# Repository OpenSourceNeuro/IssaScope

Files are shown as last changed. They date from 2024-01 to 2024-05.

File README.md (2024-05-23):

<p align="left">
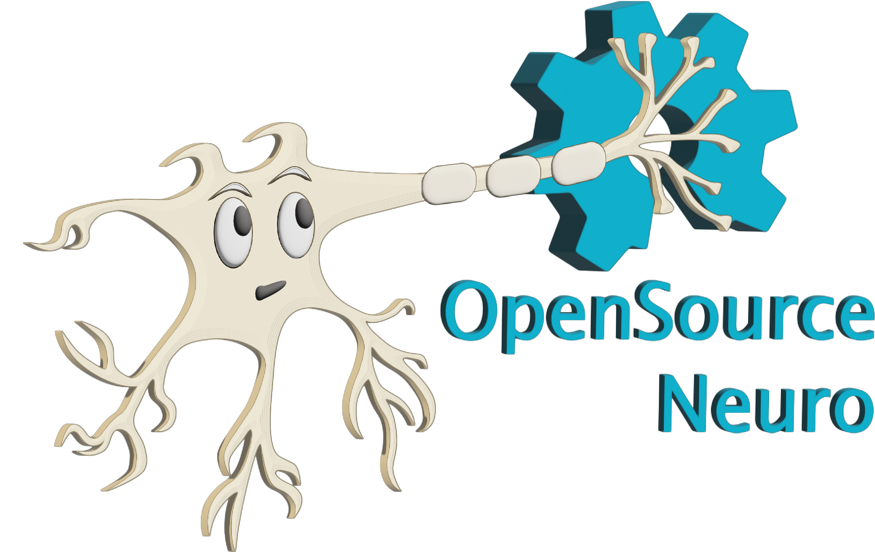
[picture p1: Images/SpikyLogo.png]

</p>

<h1 align="center"> Issa Scope v0.2</h1>
<h3 align="center">  An ethoscope for optogenetics behavioural essays</h3></p>
<h6 align="right">developed by M.J.Y. Zimmermann</h6>

<br></br>

This project is licensed under the <a href="https://www.gnu.org/licenses/gpl-3.0.html">GNU General Public License v3.0</a>

The hardware is licensed under the <a href="https://cern-ohl.web.cern.ch">CERN OHL v1.2</a>

<br></br>

***

<br></br>

- [Introduction](#Introduction)
- [EthoScope](#Ethoscope)
- [PCB](#PCB)
- [ESP32/Arduino microcontroller](#Microcontroller)
  - [Driver Installation](#Driver_Installation)
  - [Arduino Environment](#Arduino_IDE)
  - [Compiling and uploading code](#Compiling_the_code)
- [GUI](#GUI)
  - [PyQt Script](#PyQt)
  - [Scope Software](#Software)

- [To-Do-List](#To-Do-List)

<br></br>

***

<br></br>

## Introduction

<br></br>

## Ethoscope
<p align="justify">
The Ethoscope consists of 15mm extruded aluminium bars purchased from <a href="https://www.makerbeam.com/makerbeamxl/">MakerBeam</a> (XL profile), and 3D printed parts.
</p>

<br></br>

## PCB
<br>
<div align= "justify">

<p>
Dedicated PCBs for all electronics components contained in the scope base and platform stimulating LEDs can be found <a href="https://github.com/OpenSourceNeuro/IssaScope/tree/main/PCB"><strong>here</strong></a> along with detailed instructions to reproduce and adapt them.
</p>

<br></br>
<h3 align="left">Ethoscope Main Board</h3></p>

<p>
The PCB is built around an <a href="https://www.espressif.com/en/products/socs/esp32">ESP32</a>, a microcontroller which exchanges signals with the recording setup, and the <a href="https://www.ti.com/lit/ds/symlink/tlc5947.pdf">TLC5947 LED driver</a>, which allows linear intensity control over all stimulating lights. The microcontroller runs on C++ however, users do not need to interfere with the source code as we provide an intuitive and interactive <a href="">Graphical User Interface</a> (GUI), from which all functions and variables can be manipulated.
</p>

<p align="center">
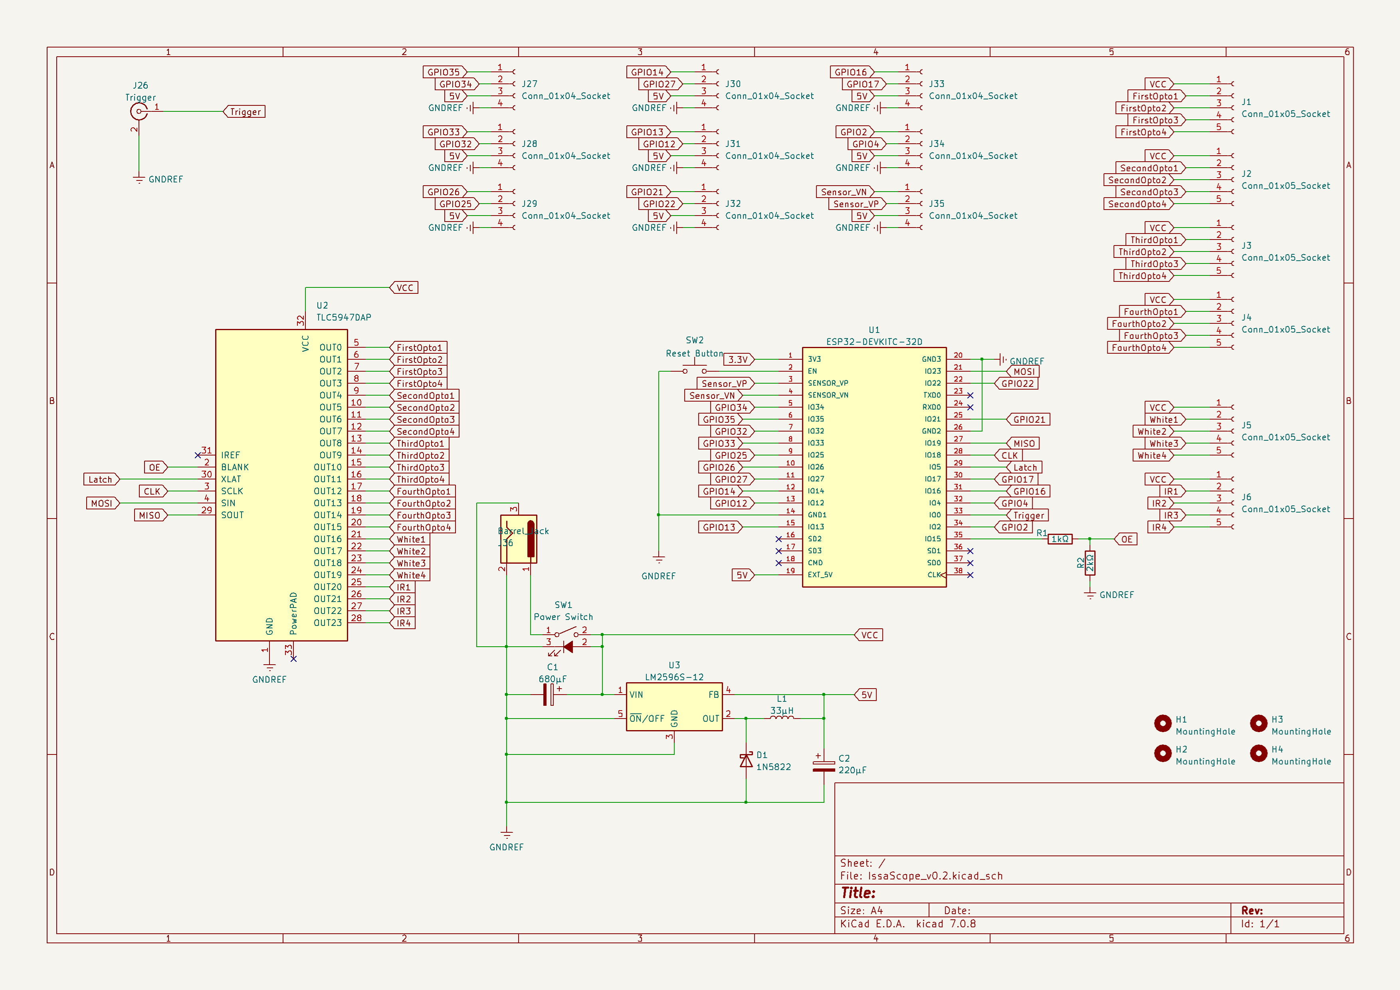
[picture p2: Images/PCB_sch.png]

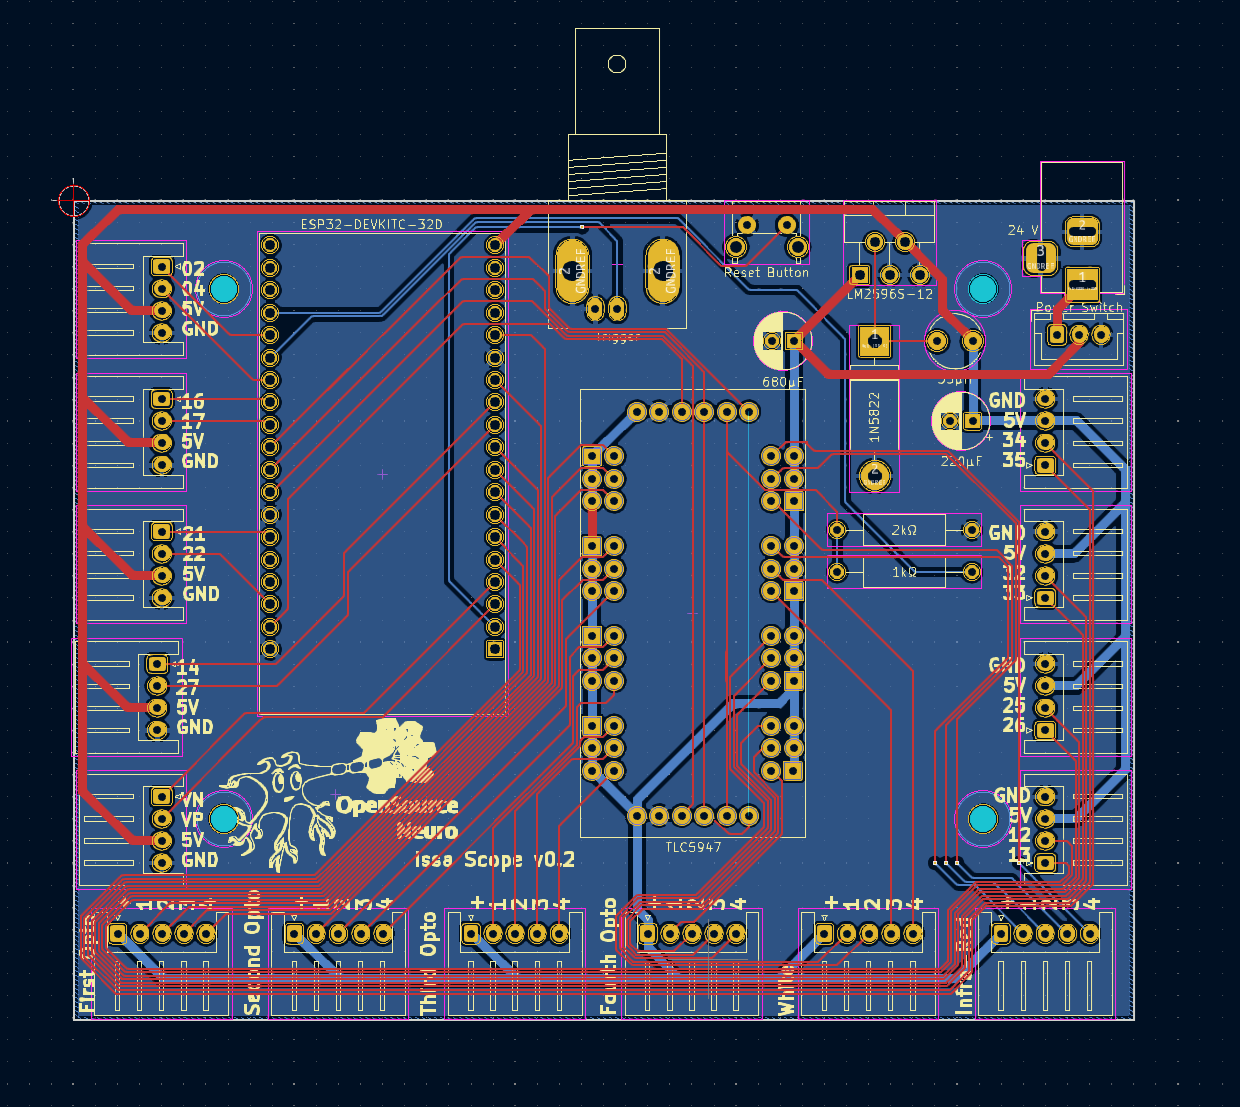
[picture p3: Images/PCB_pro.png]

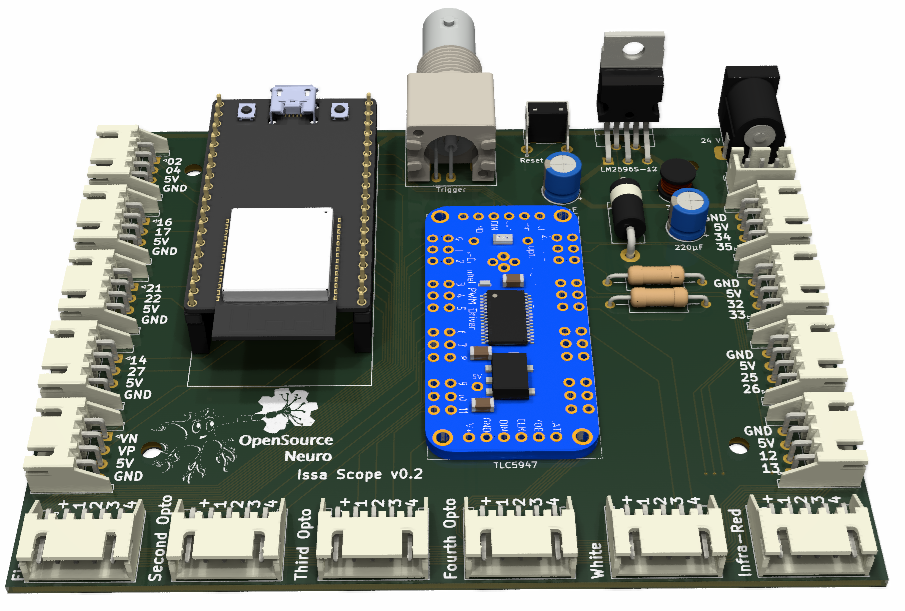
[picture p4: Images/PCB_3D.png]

</p>

<h5 align="center"> <em>Left: </em>PCB schematics for the IssaScope v0.2, <em>Middle: PCB layout for manufacturing</em>, <em>Right: </em>Rendering of the board populated with electronics components</h5>

<br>

<p>
The board provides connections via Molex JST plugs for 4 * four LED channels meant to be used for 4 * four distinct optogenetics light sources.

It also provides ports for base illumination for both white and infra red lights, designed for providing light below the samples.

Remaining ports provide access to unuse GPIO pins on the microcontroller for further upgrade (I/O signals, sensors, motors, etc.)

The board takes a 24V input, a tension above this value will result in damaging the board components.
</p>

<br></br>

<p>
This repository contains detailed <a href="https://github.com/OpenSourceNeuro/OpenSpritzer-V2/blob/main/Installation_Manual.md">assembly instructions and an operation manual</a> for the Scope electronics assembly. The <a href="https://github.com/OpenSourceNeuro/OpenSpritzer-V2/blob/main/BOM.csv">bill of material</a> details all components required.
</p>

<p>
To simplify the wiring assembly, a customed circuit board has been designed. PCB prototype companies (i.e. <a href="jlcpcb.com"> JLCPCB</a>) will only require the <a href="https://github.com/OpenSourceNeuro/IssaScope/tree/main/PCB/IssaScope_gerbers  "> gerber.zip</a> folder to be sent to them for production.
</p>

</div>
<br></br>

## Microcontroller

#### Driver_Installation
<br>
<div align= "justify">

<p>
IssaScope v0.2 firmware runs on an Espressif ESP32 board and requires the USB to UART bridge <a href="https://www.silabs.com/developers/usb-to-uart-bridge-vcp-drivers"> CP210x driver</a>,  which can be downloaded<a href="https://www.silabs.com/developers/usb-to-uart-bridge-vcp-drivers?tab=downloads"> <strong>here</strong></a>.
</p>

<p>
Once the driver has been installed, users can upload and modify the <a href="https://https://github.com/OpenSourceNeuro/IssaScope/tree/main/Arduino/IssaScope.com/OpenSourceNeuro/OpenSpritzer-V2/tree/main/Arduino/OpenSpritzer_V2">microcontroller code</a> through the <a href="https://www.arduino.cc/en/software">Arduino IDE</a> (Integrated Development Environment).
</p>

</div>
<br></br>

##### Arduino_IDE
<br>
<div align="justify">

<p>
The ESP32 microcontroller runs a C++ code which can be accessed via the Arduino IDE, which can be downloaded <a href="https://www.arduino.cc/en/software"><strong>here</strong></a>.
</p>

<br></br>

<p>
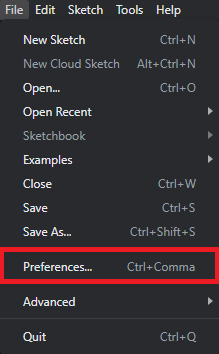
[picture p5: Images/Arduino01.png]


Once the IDE is installed, users needs to install the ESP32 board library:

In the Arduino IDE, go to <strong> File > Preferences </strong>

Enter the following link into the <strong>Additional Board Manager URLs</strong> field:

https://raw.githubusercontent.com/espressif/arduino-esp32/gh-pages/package_esp32_index.json
</p>

<br></br>

<p>
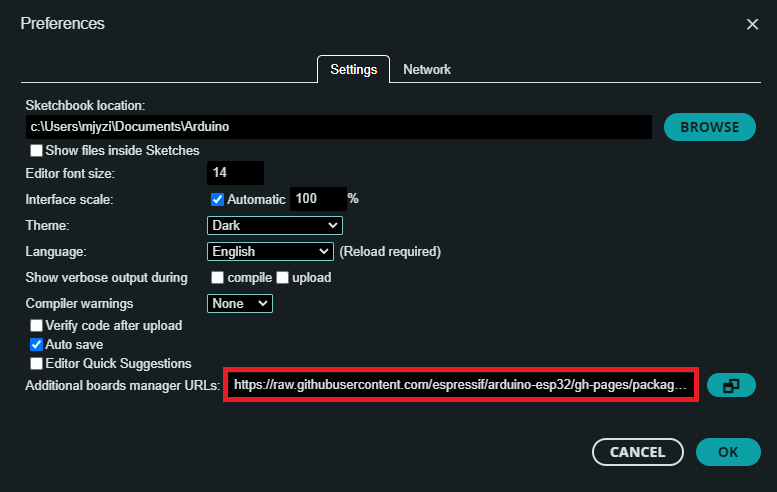
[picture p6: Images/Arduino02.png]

Then click on the <strong>OK</strong> button.
</p>

<br></br>

<p>
Next, open the Boards Manager. Go to <strong> Tools > Board > Board Manager...</strong>

Search for ESP32 and press install button for the <strong>ESP32 by Espressif Systems</strong>.
</p>

<br></br>

<p>
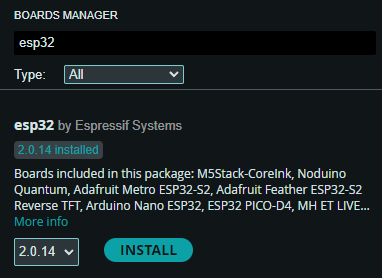
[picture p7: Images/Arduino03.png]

Then click on the <strong>Install</strong> button.
</p>

<br></br>

<p>
Finally and in a smiilar manner the library <strong>Adafruit_TLC5947</strong> needs to be installed.
</p>

</div>
<br></br>

##### Compiling_the_code
<br>
<div align= "justify">

<p>
Within the Arduino IDE, user needs to select the FQBN (Fully Qualified Board Name) on which the code will be compiled for.

Here the ESP32 Dev Module needs to be selected.

Go to <strong>Tools > Board > esp32 > ESP32 Dev Module </strong>


The board name should be displayed  as shown.
</p>

</div>
<br></br>

## GUI
<div align="justify">

<p>
A Graphical User Interface (GUI) dedicated to this project was designed using the python PyQt6/PySide6 libraries. The entire script can be found <a href="https://github.com/OpenSourceNeuro/IssaScope/tree/main/GUI/PyQt"><strong>here</strong></a>.
</p>

</div>
<br></br>

#### PyQt
<br>
<div align="justify">

githubusercontent

<br></br>

#### Software
<br>
<div align="justify">

<p>
The python script for the GUI can be run directly from a python environment, or run from a <strong>.exe</strong> file which can be found <a href=""><strong>here</strong></a>
</p>

<p>
On the main screen, Users can fi
</p>

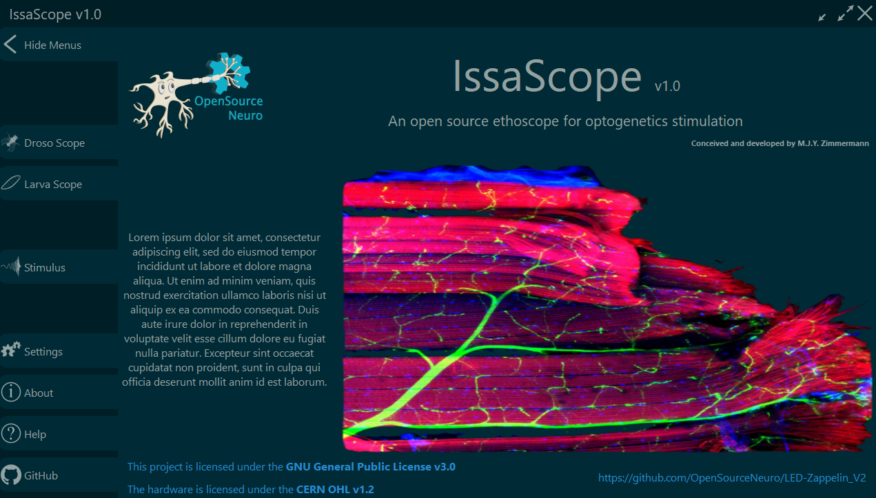
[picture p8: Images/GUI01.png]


</div>
<br></br>

## To-Do-List
<br>
<div align="justify">

- Find suitable material for close up hanging LEDs
- Make an equivalent to the GUI using Bonsai

</div>
<br></br>

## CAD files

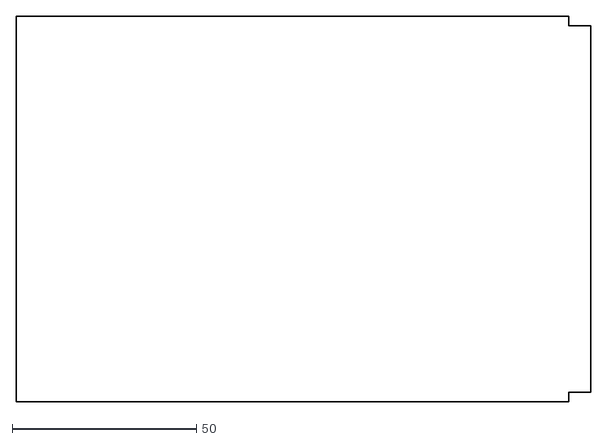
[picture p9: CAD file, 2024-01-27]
3D/DXF/BasePanel.dxf
156.0 x 104.5

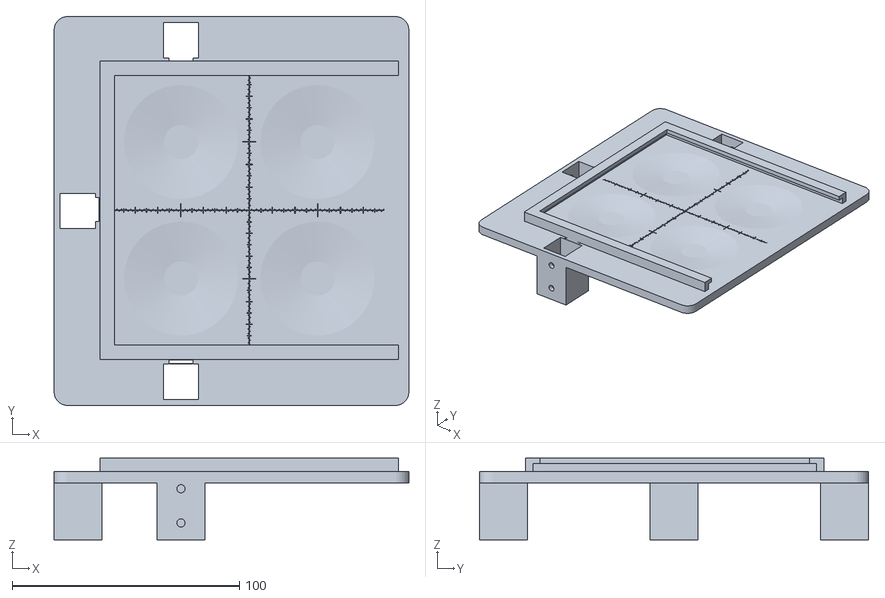
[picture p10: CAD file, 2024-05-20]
3D/STL/IssaScope_Arena.stl
156.0 x 171.0 x 36.0

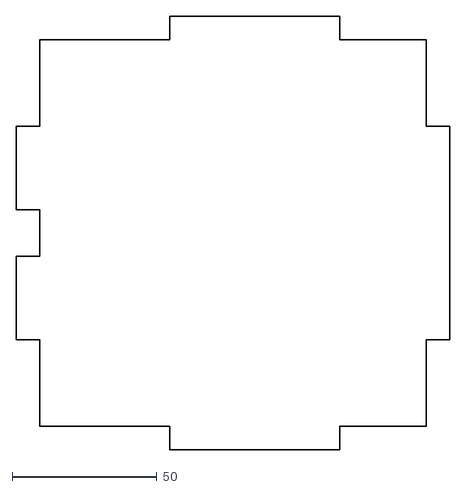
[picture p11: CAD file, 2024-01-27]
3D/DXF/Platform.dxf
150.0 x 150.0

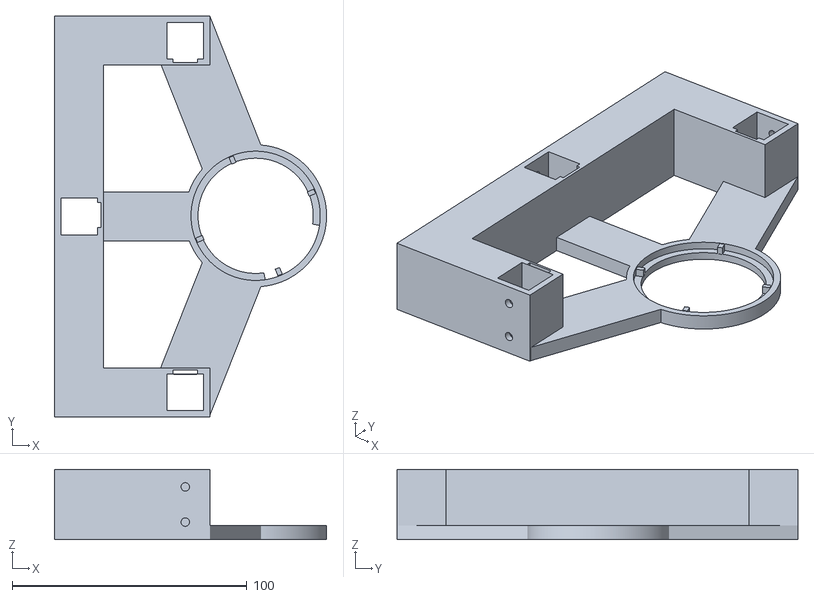
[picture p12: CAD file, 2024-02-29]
3D/STL/IssaScope_IRCamHolder.stl
116.0 x 171.0 x 30.0

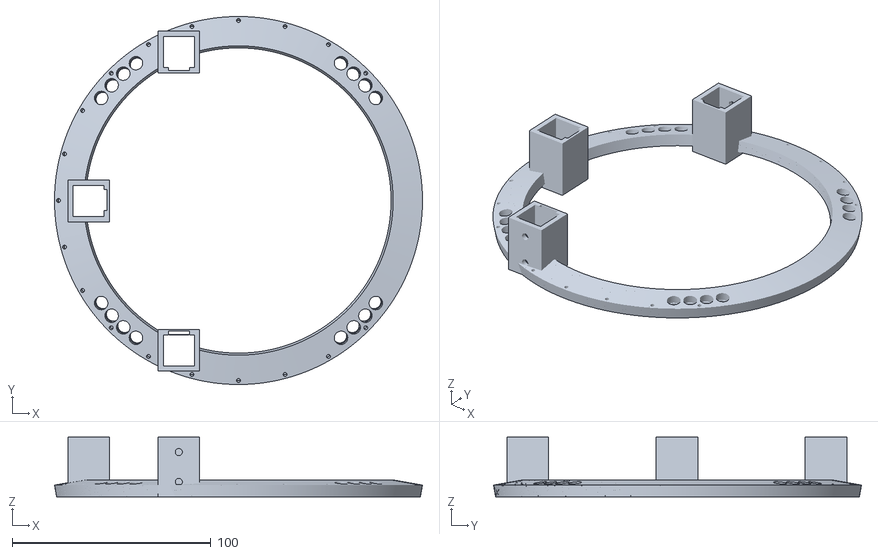
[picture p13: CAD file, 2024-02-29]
3D/STL/IssaScope_Opto.stl
185.0 x 185.0 x 30.0

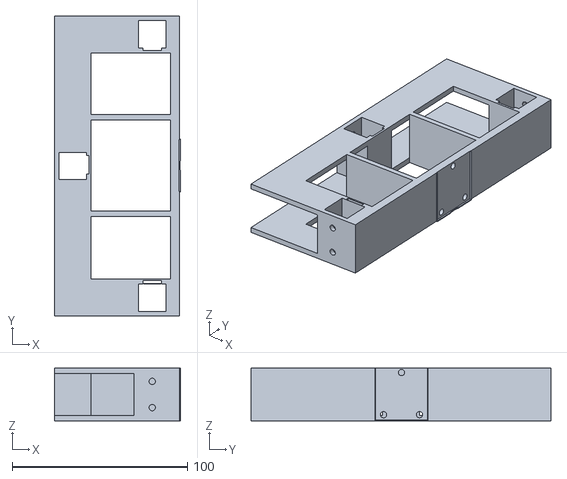
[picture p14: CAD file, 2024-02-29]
3D/STL/IssaScope_BaslerHolder.stl
72.0 x 171.0 x 30.0

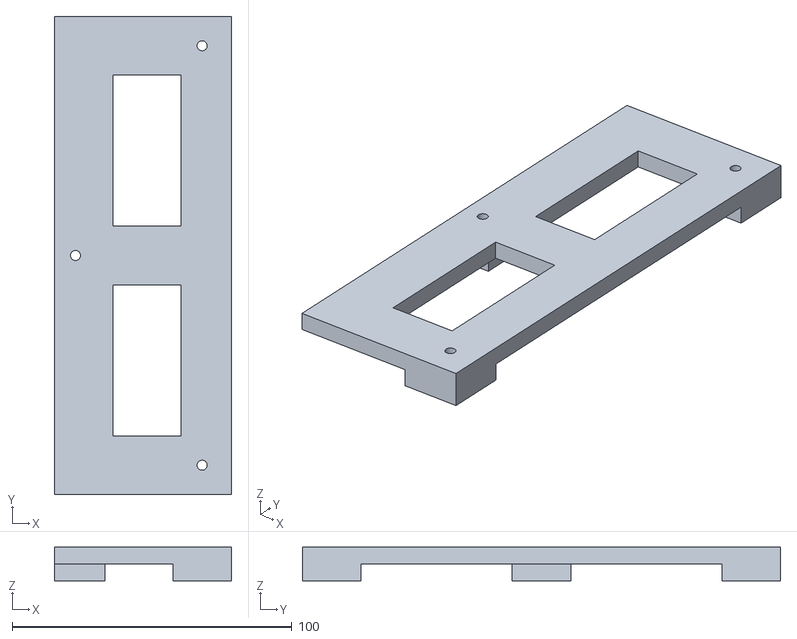
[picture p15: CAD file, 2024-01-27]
3D/STL/IssaScope_Top.stl
63.3 x 171.0 x 12.0

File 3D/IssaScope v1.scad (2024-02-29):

tol = 0.3;
Wall = 3;
M3 = 3/2+tol;
Smoothness = 100;


x_alu = 15;
x_corner = 45;
x_link = 10;
z_link = 1.5+tol;
alu_groove = 3;

z_slider = 30;

l_Extru01 = 150;
l_Extru02 =  50;
l_Extru03 =  300;
l_Extru04 =  200;
LED_Colour = [[1,0,0],[0,1,0],[0,0,1],[1,1,0]];
LED_Colour_Light = [[1,0,0,0.1],[0,1,0,0.1],[0,0,1,0.1],[1,1,0,0.1]];

LED = 5/2;
r_LED = 6.2/2+tol;
R_LED = 7.5/2+tol;
h_LED = 1.5;

Platform = 10;
Base = 10;
Top = 10;
Basler = 10;
Basler_Holder = 10;
IR_Cam_Holder = 1;
Basler_Holder_Full = 1;
LED_Holder = 10;
5mm_LED = 10;
Illumination = 10;
Optogenetics = 10;
 
if (Platform == 1){Platform();}
if (Base == 1){Base();} 
if (Top == 1){Top();} 
if (Basler == 1){translate([0,0,2*x_alu+l_Extru02+2/3*l_Extru03+l_Extru04+z_slider])Basler();} 
if (Basler_Holder == 1){Basler_Holder();} 
if (IR_Cam_Holder == 1){IR_Cam_Holder();} 
if (LED_Holder == 1){LED_Holder();}
if (Optogenetics == 1){translate([0,0,Opto_Height])Optogenetics();}


module Platform(){
    color([0.8,0.8,0.8,0.5])translate([x_alu/2,x_alu/2,l_Extru02+1.5*x_alu])cube([l_Extru01,l_Extru01,Wall]);
}
module Base(){
    translate([0,0,x_alu])rotate([0,90,0]){
        Alu_Extru(l_Extru01);
        translate([0,0,l_Extru01+x_alu])rotate([-90,0,0])Alu_Extru(l_Extru01);
        translate([0,l_Extru01+x_alu,l_Extru01+x_alu])rotate([-180,0,0])Alu_Extru(l_Extru01);
        translate([0,l_Extru01+x_alu,0])rotate([-270,0,0])Alu_Extru(l_Extru01);
    }
    
    translate([x_alu,l_Extru01-x_alu,x_alu])Alu_Extru(l_Extru02);
    translate([l_Extru01-x_alu,l_Extru01-x_alu,x_alu])Alu_Extru(l_Extru02);
    translate([x_alu,x_alu,x_alu])Alu_Extru(l_Extru02);
    translate([l_Extru01-x_alu,x_alu,x_alu])Alu_Extru(l_Extru02);
    
    translate([0,0,x_alu+l_Extru02+x_alu])rotate([0,90,0]){
        Alu_Extru(l_Extru01);
        translate([0,0,l_Extru01+x_alu])rotate([-90,0,0])Alu_Extru(l_Extru01);
        translate([0,l_Extru01+x_alu,l_Extru01+x_alu])rotate([-180,0,0])Alu_Extru(l_Extru01);
        translate([0,l_Extru01+x_alu,0])rotate([-270,0,0])Alu_Extru(l_Extru01);
    }
    
    translate([0,0,2*x_alu+l_Extru02])Alu_Corner();
    translate([l_Extru01+x_alu,0,2*x_alu+l_Extru02])rotate([0,0,90])Alu_Corner();
    translate([l_Extru01+x_alu,l_Extru01+x_alu,2*x_alu+l_Extru02])rotate([0,0,180])Alu_Corner();
    translate([0,l_Extru01+x_alu,2*x_alu+l_Extru02])rotate([0,0,270])Alu_Corner();
    
    translate([x_corner+tol,0,2*x_alu+l_Extru02])Alu_Extru(l_Extru03+l_Extru04);
    translate([x_corner+tol,l_Extru01,2*x_alu+l_Extru02])Alu_Extru(l_Extru03+l_Extru04);
    translate([0,l_Extru01/2,2*x_alu+l_Extru02])Alu_Extru(l_Extru03+l_Extru04);
    
    translate([x_corner-x_alu+tol,0,x_alu+l_Extru02])rotate([90,0,0])Alu_Te();
    translate([x_corner-x_alu+tol,l_Extru01+x_alu+1,x_alu+l_Extru02])rotate([90,0,0])Alu_Te();
    translate([-1,l_Extru01/2-x_alu,x_alu+l_Extru02])rotate([90,0,90])Alu_Te();
}


module Top(){
    translate([x_corner,-Wall,x_alu+l_Extru02+x_alu+l_Extru03+l_Extru04-Wall]){
        difference(){
            union(){
                cube([x_alu+Wall,l_Extru01+x_alu+2*Wall,2*Wall]);
                translate([-x_corner-tol,0,0])cube([x_alu+2*Wall,l_Extru01+x_alu+2*Wall,2*Wall]);
                translate([-x_corner-tol,0,0])cube([x_alu+tol+x_corner,x_alu+2*Wall,2*Wall]);
                translate([-x_corner-tol,l_Extru01,0])cube([x_alu+tol+x_corner,x_alu+2*Wall,2*Wall]);
                translate([-x_corner-tol,l_Extru01/2,0])cube([x_alu+tol+x_corner,x_alu+2*Wall,2*Wall]);
            }
            translate([0,Wall,-tol])cube([x_alu+2*tol,x_alu+2*tol,Wall]);
            translate([0,Wall+l_Extru01,-tol])cube([x_alu+2*tol,x_alu+2*tol,Wall]);
            translate([-x_corner-tol,Wall+l_Extru01/2,-tol])cube([x_alu+2*tol,x_alu+2*tol,Wall]);
            
            translate([x_alu/2,x_alu/2+Wall,-tol])cylinder(r=M3,h=3*Wall,$fn=Smoothness);
            translate([x_alu/2,x_alu/2+Wall+l_Extru01,-tol])cylinder(r=M3,h=3*Wall,$fn=Smoothness);
            translate([x_alu/2-x_corner-tol,x_alu/2+Wall+l_Extru01/2,-tol])cylinder(r=M3,h=3*Wall,$fn=Smoothness);
        }
        
        difference(){
            union(){
                translate([-Wall,0,-2*Wall])cube([x_alu+2*Wall,x_alu+2*Wall,2*Wall]);
                translate([-Wall,l_Extru01,-2*Wall])cube([x_alu+2*Wall,x_alu+2*Wall,2*Wall]);
                translate([-x_corner-tol,l_Extru01/2,-2*Wall])cube([x_alu+Wall,x_alu+2*Wall,2*Wall]);
            }
            translate([0,Wall,-2*Wall-tol])cube([x_alu+2*tol,x_alu+2*tol,2*Wall+tol]);
            translate([0,Wall+l_Extru01,-2*Wall-tol])cube([x_alu+2*tol,x_alu+2*tol,2*Wall+tol]);
            translate([-x_corner-tol,Wall+l_Extru01/2,-2*Wall-tol])cube([x_alu+2*tol,x_alu+2*tol,2*Wall+tol]);
        }
    }
}





module Basler(){
    x_Basler = 29.5;
    y_Basler = 29.5;
    z_Basler = 29.5;
    r_Basler = 28.5/2;
    h_Basler = 43;
    z1 = 2.5;
    z2 = 26.5;
    y = 4.5;

    color([1,0,0])translate([(l_Extru01+x_alu)/2,(l_Extru01+x_alu)/2,0])rotate([-180,0,180]){
    translate([-x_Basler/2,-y_Basler/2,0])cube([x_Basler,y_Basler,z_Basler]);
    translate([0,0,z_Basler])cylinder(r=r_Basler,h=h_Basler,$fn=Smoothness);
    
    translate([x_Basler/2,0,z1])rotate([0,90,0])cylinder(r=M3,h=4*Wall,$fn=Smoothness);
    translate([x_Basler/2,y_Basler/2-y,z2])rotate([0,90,0])cylinder(r=M3,h=4*Wall,$fn=Smoothness);
    translate([x_Basler/2,-y_Basler/2+y,z2])rotate([0,90,0])cylinder(r=M3,h=4*Wall,$fn=Smoothness);
    }

    
    
}
module IR_Cam_Holder(){
    r_CameraHolder = 54.5/2;
    x_pin = 2;
    y_pin = 3;
    translate([0,0,2*x_alu+l_Extru02+2/3*l_Extru03+l_Extru04]){
        
        difference(){
            union(){
                translate([x_corner+tol-Wall-tol,-Wall-tol,0])Holder_Slider();
                translate([x_corner+tol-Wall-tol,l_Extru01-Wall-tol,0])Holder_Slider();
                translate([-Wall-tol,l_Extru01/2-Wall-tol,0])Holder_Slider();   
            }
        
            translate([x_corner+x_alu/2,-Wall-M3,z_slider/4])rotate([-90,0,0])cylinder(r=M3,h=3*Wall,$fn=Smoothness);
            translate([x_corner+x_alu/2,l_Extru01+x_alu+Wall,z_slider/4])rotate([90,0,0])cylinder(r=M3,h=3*Wall,$fn=Smoothness);
            translate([-Wall-M3,x_alu/2+l_Extru01/2,z_slider/4])rotate([0,90,0])cylinder(r=M3,h=3*Wall,$fn=Smoothness);
            
            translate([x_corner+x_alu/2,-Wall-M3,z_slider*3/4])rotate([-90,0,0])cylinder(r=M3,h=3*Wall,$fn=Smoothness);
            translate([x_corner+x_alu/2,l_Extru01+x_alu+Wall,z_slider*3/4])rotate([90,0,0])cylinder(r=M3,h=3*Wall,$fn=Smoothness);
            translate([-Wall-M3,x_alu/2+l_Extru01/2,z_slider*3/4])rotate([0,90,0])cylinder(r=M3,h=3*Wall,$fn=Smoothness);
            
            translate([x_corner+x_alu/2-x_link/2-tol,x_alu,-tol])cube([x_link+2*tol,z_link,z_slider+2*tol]);
            translate([x_corner+x_alu/2-x_link/2-tol,l_Extru01-z_link-tol,-tol])cube([x_link+2*tol,z_link,z_slider+2*tol]);
            translate([x_alu-tol,(l_Extru01+x_alu)/2-x_link/2,-tol])cube([z_link,x_link+2*tol,z_slider+2*tol]);
        }

        translate([(l_Extru01+x_alu)/2,(l_Extru01+x_alu)/2,Wall])difference(){
            cylinder(r=r_CameraHolder+Wall,h=2*Wall,$fn=Smoothness);
            translate([0,0,Wall])cylinder(r=r_CameraHolder+tol,h=Wall+tol,$fn=Smoothness);
            translate([0,0,-tol])cylinder(r=r_CameraHolder-Wall+tol,h=2*Wall+tol,$fn=Smoothness);
            intersection(){
                translate([0,0,-tol])cylinder(r=r_CameraHolder+tol,h=2*Wall+tol,$fn=Smoothness);
                rotate([0,0,-90])translate([r_CameraHolder,r_CameraHolder,-tol])rotate([0,0,45])scale([1.5,1,1])cylinder(r=r_CameraHolder,h=2*Wall,$fn=4);
            }
        }
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

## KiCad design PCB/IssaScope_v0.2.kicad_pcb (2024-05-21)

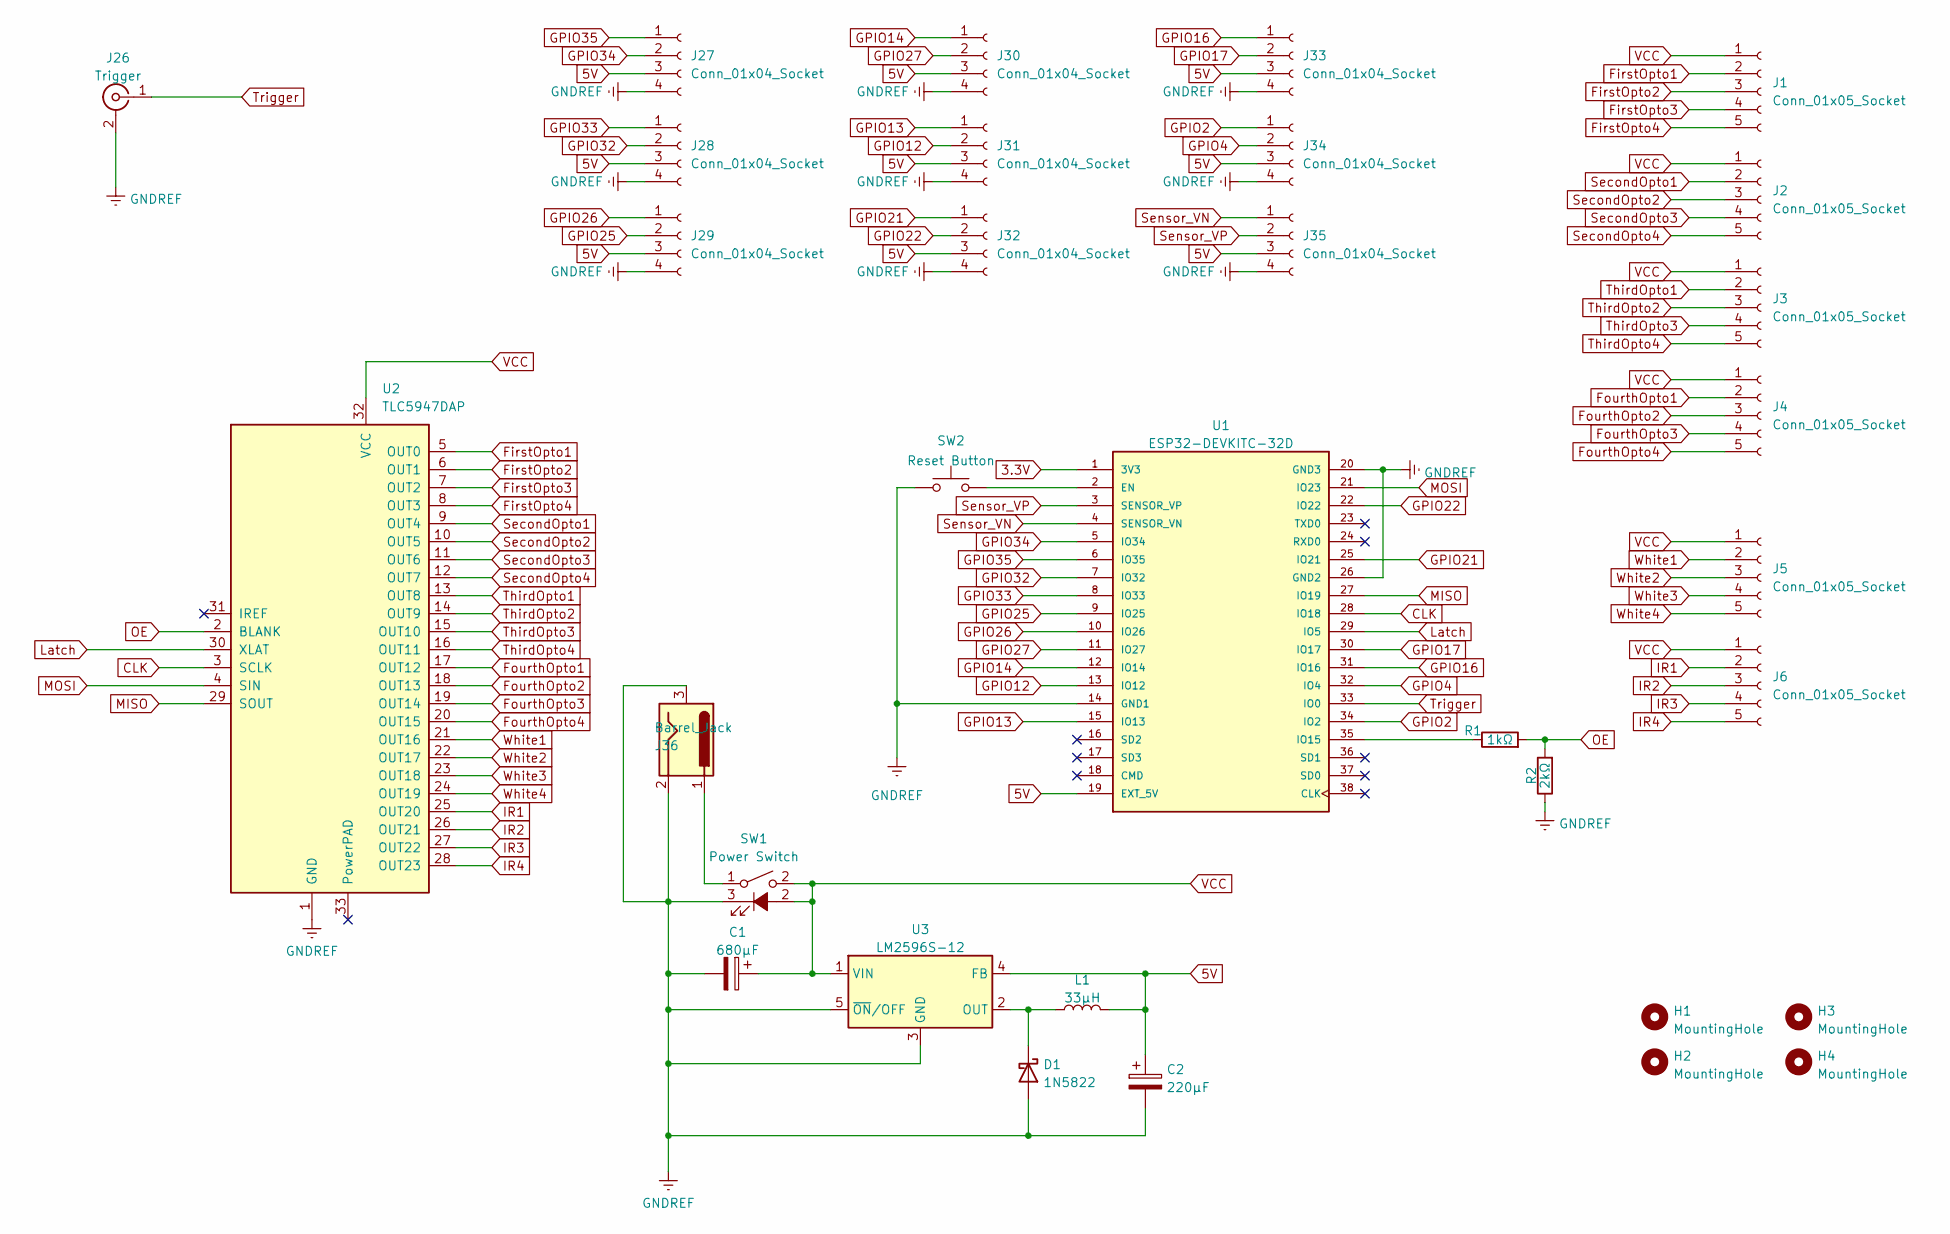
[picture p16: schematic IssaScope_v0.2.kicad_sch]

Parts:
C1: 680μF; CP_Radial_D6.3mm_P2.50mm
C2: 220μF; CP_Radial_D6.3mm_P2.50mm
D1: 1N5822; D_DO-201AD_P15.24mm_Horizontal
H1, H2, H3, H4: MountingHole; MountingHole_3mm
J1, J2, J3, J4, J5, J6: Conn_01x05_Socket; JST_XH_S5B-XH-A_1x05_P2.50mm_Horizontal
J26: Trigger; BNC_Socket_TYCO-AMP_LargePads
J27, J28, J29, J30, J31, J32, J33, J34, J35: Conn_01x04_Socket; JST_XH_S4B-XH-A_1x04_P2.50mm_Horizontal
J36: Barrel_Jack; BarrelJack_Horizontal
L1: 33μH; L_Radial_D6.0mm_P4.00mm
R1: 1kΩ; R_Axial_DIN0309_L9.0mm_D3.2mm_P15.24mm_Horizontal
R2: 2kΩ; R_Axial_DIN0309_L9.0mm_D3.2mm_P15.24mm_Horizontal
SW1: Power Switch; JST_XH_B3B-XH-A_1x03_P2.50mm_Vertical
SW2: Reset Button; SW_Tactile_SPST_Angled_PTS645Vx39-2LFS
U1: ESP32-DEVKITC-32D; MODULE_ESP32-DEVKITC-32D; PARTREV 4
U2: TLC5947DAP; Maxi_TLC5947
U3: LM2596S-12; TO-220-5_P3.4x3.7mm_StaggerOdd_Lead3.8mm_Vertical

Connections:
3.3V: U1.1 (3V3)
5V: C2.1, J27.3, J28.3, J29.3, J30.3, J31.3, J32.3, J33.3, J34.3, J35.3, L1.2, U1.19 (EXT_5V), U3.4 (FB)
CLK: U1.28 (IO18), U2.3 (SCLK)
FirstOpto1: J1.2, U2.5 (OUT0)
FirstOpto2: J1.3, U2.6 (OUT1)
FirstOpto3: J1.4, U2.7 (OUT2)
FirstOpto4: J1.5, U2.8 (OUT3)
FourthOpto1: J4.2, U2.17 (OUT12)
FourthOpto2: J4.3, U2.18 (OUT13)
FourthOpto3: J4.4, U2.19 (OUT14)
FourthOpto4: J4.5, U2.20 (OUT15)
GNDREF: C1.2, C2.2, D1.2 (A), J26.2 (Ext), J27.4, J28.4, J29.4, J30.4, J31.4, J32.4, J33.4, J34.4, J35.4, J36.2, J36.3, R2.1, SW1.3 (K), SW2.1, U1.14 (GND1), U1.20 (GND3), U1.26 (GND2), U2.1 (GND), U3.3 (GND), U3.5 (~ON/OFF)
GPIO2: J34.1, U1.34 (IO2)
GPIO4: J34.2, U1.32 (IO4)
GPIO12: J31.2, U1.13 (IO12)
GPIO13: J31.1, U1.15 (IO13)
GPIO14: J30.1, U1.12 (IO14)
GPIO16: J33.1, U1.31 (IO16)
GPIO17: J33.2, U1.30 (IO17)
GPIO21: J32.1, U1.25 (IO21)
GPIO22: J32.2, U1.22 (IO22)
GPIO25: J29.2, U1.9 (IO25)
GPIO26: J29.1, U1.10 (IO26)
GPIO27: J30.2, U1.11 (IO27)
GPIO32: J28.2, U1.7 (IO32)
GPIO33: J28.1, U1.8 (IO33)
GPIO34: J27.2, U1.5 (IO34)
GPIO35: J27.1, U1.6 (IO35)
IR1: J6.2, U2.25 (OUT20)
IR2: J6.3, U2.26 (OUT21)
IR3: J6.4, U2.27 (OUT22)
IR4: J6.5, U2.28 (OUT23)
Latch: U1.29 (IO5), U2.30 (XLAT)
MISO: U1.27 (IO19), U2.29 (SOUT)
MOSI: U1.21 (IO23), U2.4 (SIN)
unnamed: D1.1 (K), L1.1, U3.2 (OUT)
unnamed: J36.1, SW1.1
unnamed: SW2.2, U1.2 (EN)
unnamed: R1.1, U1.35 (IO15)
OE: R1.2, R2.2, U2.2 (BLANK)
SecondOpto1: J2.2, U2.9 (OUT4)
SecondOpto2: J2.3, U2.10 (OUT5)
SecondOpto3: J2.4, U2.11 (OUT6)
SecondOpto4: J2.5, U2.12 (OUT7)
Sensor_VN: J35.1, U1.4 (SENSOR_VN)
Sensor_VP: J35.2, U1.3 (SENSOR_VP)
ThirdOpto1: J3.2, U2.13 (OUT8)
ThirdOpto2: J3.3, U2.14 (OUT9)
ThirdOpto3: J3.4, U2.15 (OUT10)
ThirdOpto4: J3.5, U2.16 (OUT11)
Trigger: J26.1 (In), U1.33 (IO0)
VCC: C1.1, J1.1, J2.1, J3.1, J4.1, J5.1, J6.1, SW1.2, U2.32 (VCC), U3.1 (VIN)
White1: J5.2, U2.21 (OUT16)
White2: J5.3, U2.22 (OUT17)
White3: J5.4, U2.23 (OUT18)
White4: J5.5, U2.24 (OUT19)

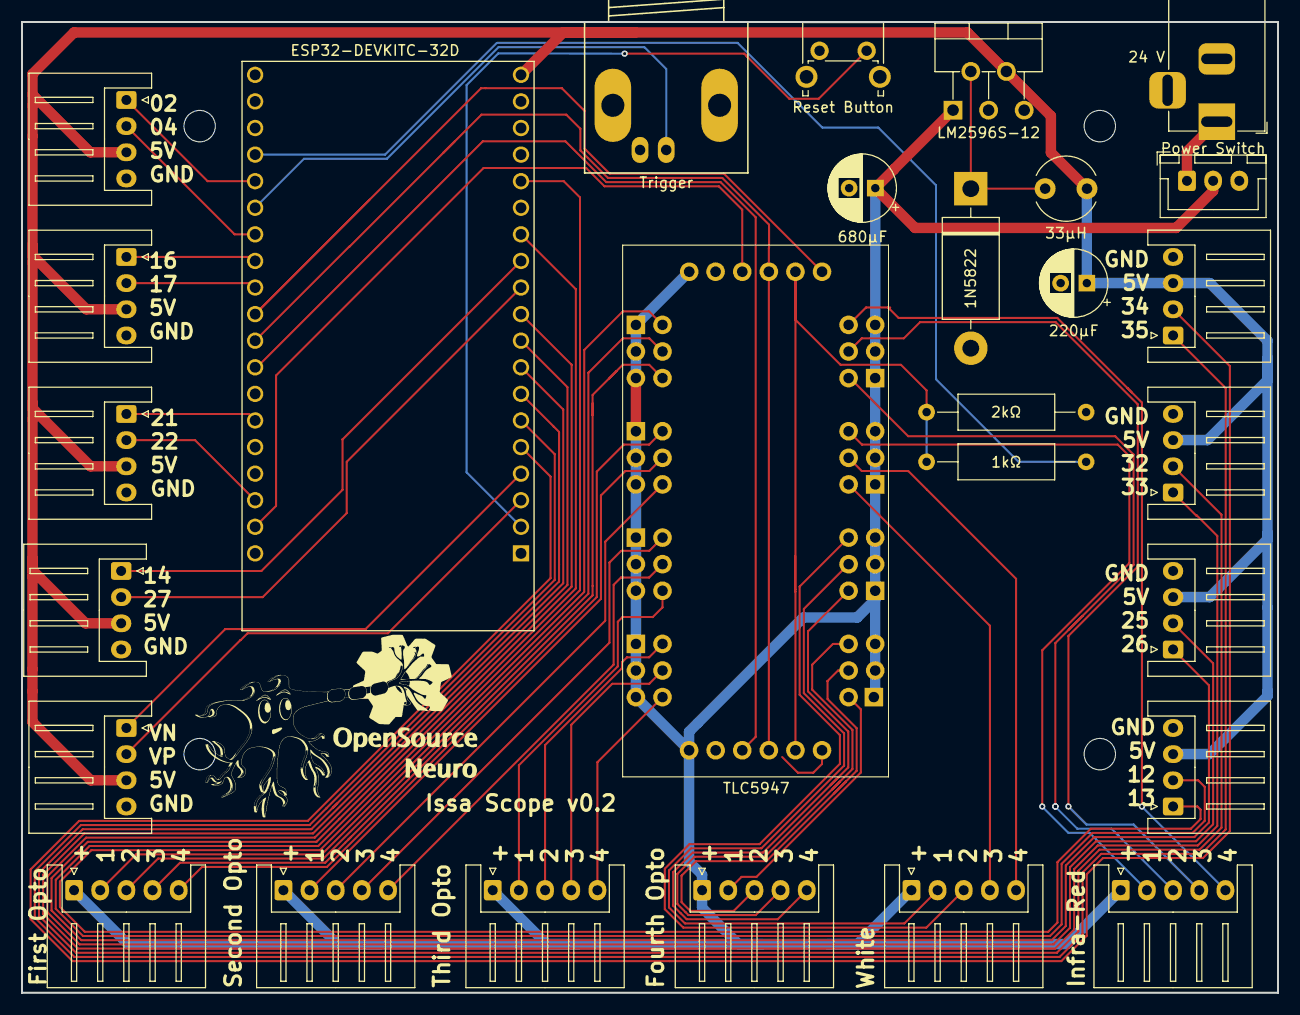
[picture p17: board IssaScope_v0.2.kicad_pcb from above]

Board: 2 copper layers, 120.0 x 92.8 mm, 32 parts (0 on the bottom side), 55 nets.

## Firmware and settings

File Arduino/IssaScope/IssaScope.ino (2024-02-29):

#include "Serial_functions.h"

/* ----------------------------------------------------------------------------------*/
/* --------------------------- Settings and Initialisings ---------------------------*/

void setup() {
  HardwareSettings();             // Load Hardware Settings as described in "General_Settings.h"
  Connection();                   // Light up LED in sequence when the stimulator is reset
  SCmdAddCommand();               // Initiate Serial Command actions
}

/* ----------------------------------------------------------------------------------*/
/* ----------------------------------- Main Loop ------------------------------------*/
  
void loop() {
  SCmd.readSerial();                                 // Wait for Serial Command
  
  CurrentMillis = millis();                          // Pick up current running time in milliseconds
  DiffMillis = CurrentMillis - PreviousMillis;       // Calculate 
  tDiffMillis = CurrentMillis - tPreviousMillis;

  if (PreAdaptationFlag == false){
    if (DiffMillis >= ResolutionMillis) {
      PreviousMillis = millis();

      if (StimulusFlag == true){
        Serial.println(i);
        i += 1;
        if(i >= iLoop){
          i = 1;
        }
      }
    }
  }
  
  if (PreAdaptationFlag == true){
    if (DiffMillis >= PreAdaptMillis) {
      PreviousMillis = millis();
      PreAdaptationFlag = false;

      if (StimulusFlag == true){
        Serial.println(i);
        i += 1;
      }
    }
  }


 
  if (tDiffMillis >= TriggerTime ) {
    tPreviousMillis = millis();

    if (StimulusFlag == true){
  
      if (TriggerModeFlag == true) {
        TriggerFlag = true;
        tPreviousMillis = CurrentMillis;
        digitalWrite(Trigger, HIGH);
        
        tr +=1;
        if (tr >= TriggerMode){
          tr = 0;
        }    
        TriggerTime = TriggerArray[tr];
      }
    }
  }

  if (TriggerFlag == true){ 

    if (CurrentMillis >= tPreviousMillis+TriggerDuration){
      digitalWrite(Trigger, LOW);
      TriggerFlag = false;
    }
  }
}

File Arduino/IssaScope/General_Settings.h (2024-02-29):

/*          ---  General Settings  ---
*/
  #include <SPI.h>                            // Include the arduino serial port interface library
  #include "Adafruit_TLC5947.h"               // Include the Adafruit TLC5947 libvrary. For better result one may change the number of channel defined in the Adafruit_TLC5947.cpp library

  #define   MISO           23                 // TLC SPI connection, Data Out
  #define   MOSI           19                 // TLC SPI connection, Data In 
  #define   CLK            18                 // TLC SPI connection, Clock 
  #define   latch          5                  // TLC Latch
  #define   Blank          17                 // TLC Ouput Enable, Also Optional feature to prevent LED to light up when powering up the TLC board
  #define   Trigger        33                 // Stimulus Tirgger channel output

  Adafruit_TLC5947 tlc = Adafruit_TLC5947(1, CLK, MISO, latch);

/* ----------------------------------------------------------------------------------*/
/* ------------------------------- Global Variables ---------------------------------*/

  word           BaudRate      = 921600;      // Baud Rate speed
  char           sCmd;                        // Serial monitor 
  float          aNumber;
  char           *arg;
  int            LED_Power     = 4095;


  int opto0 =  0;
  int opto1 =  1;
  int opto2 =  2;
  int opto3 =  3;
  int Opto_LED_Array[]{opto0, opto1, opto2, opto3};

  int  w0  =   8;
  int  w1  =   9;
  int  w2  =  10;
  int  w3  =  11;
  int  w4  =  12;
  int  w5  =  13;
  int  w6  =  14;
  int  w7  =  15;
  int White_LED_Array[]{w0, w2, w1, w3, w4, w6, w5, w7};

  int  r0  =  16;
  int  r1  =  17;
  int  r2  =  18;
  int  r3  =  19;
  int  r4  =  20;
  int  r5  =  21;
  int  r6  =  22;
  int  r7  =  23;
  int IR_LED_Array[]{r0, r2, r1, r3, r4, r6, r5, r7};


bool           StimulusFlag = false;
bool           flag;
int            i;                           // Iteration loop factor
int            iLoop;
int            CurrentMillis;               // Current Microsecond clock
int            PreviousMillis;              // Microsecond clock stamp
int            DiffMillis;                  // Difference in microseconds between the clock and the stamp
int            tPreviousMillis;             // Microsecond clock stamp
int            tDiffMillis;                 // Difference in microseconds between the clock and the stamp
int            tdPreviousMillis;            // Microsecond clock stamp
int            tdDiffMillis;                // Difference in microseconds between the clock and the stamp
int            ResolutionMillis;            // Microseconds delay between two i iteration
int            PreAdaptMillis;              // Preadaptation period in microseconds
bool           PreAdaptationFlag;
bool           TriggerModeFlag;
int            TriggerMode;                 // Set the Trigger mode
int            TriggerArray[100];

int            t;                           // Trigger counter
int            td;                          // Trigger Pulse counter
int            tr;                          // TriggerTime array counter
bool           TriggerFlag = false;         // Trigger Flag
int            TriggerTime;                 // Lenght of the Trigger loop in ms 
int            TriggerDuration = 100000;    // Length of the Trigger signal in us 

int            l;                           // LED iteration factor


/* ----------------------------------------------------------------------------------*/
/* ----------------------------- Initialising conditions ----------------------------*/

void HardwareSettings(){
// Set pins
  pinMode(Trigger, OUTPUT);  
  digitalWrite(Trigger, LOW);  

// Initialise the serial communication with PC
  Serial.begin(BaudRate);                      
  
// Initialise the Adafruit TLC driver 
  tlc.begin();
  tlc.write();  

// Initialise parameters
  l = 0;
  t = 0;
  td = 0;
  TriggerFlag = false;
  CurrentMillis = 0;
  PreviousMillis = 0;
  DiffMillis = 0;
  tPreviousMillis = 0;
  tDiffMillis = 0;
  tdPreviousMillis = 0;
  flag = true;
}

/* ----------------------------------------------------------------------------------*/
/* -----------------------------------  Connection ----------------------------------*/
void Connection(){
  for (int i = 0; i <= 7; i++) {
    tlc.setPWM(White_LED_Array[i],LED_Power);                        
    tlc.write();
    delay(100);
  }
  for (int i = 0; i <= 7; i++) {
    tlc.setPWM(White_LED_Array[i],0);                        
    tlc.write();
  }
}

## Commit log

2024-01-27 Create 3D folder
    [BasePanel.dxf, IssaScope v1.scad, IssaScope_BaslerHolder.stl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]
2024-01-27 create Arduino folder
2024-02-29 Update 3D
    [IssaScope v1.scad, IssaScope_BaslerHolder.stl, IssaScope_IRCamHolder.stl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]
2024-02-29 update Arduino
2024-02-29 update GUI
    [AmplitudeChirp_3Hz.csv, ExponentialChirp_10Hz.csv, OnOff_All_3sec.csv]
2024-05-20 upload 3D files
    [BasePanel.dxf, IssaScope_Arena.stl, IssaScope_BaslerHolder.stl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]
2024-05-21 update PCB
    [IssaScope_v0.2-B_Cu.gbr, IssaScope_v0.2-B_Mask.gbr, IssaScope_v0.2-B_Paste.gbr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]
2024-05-23 update GUI files
    [AmplitudeChirp_3Hz.csv, ExponentialChirp_10Hz.csv, OnOff_All_3sec.csv]
